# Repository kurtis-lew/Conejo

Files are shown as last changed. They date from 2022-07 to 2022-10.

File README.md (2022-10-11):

# Conejo
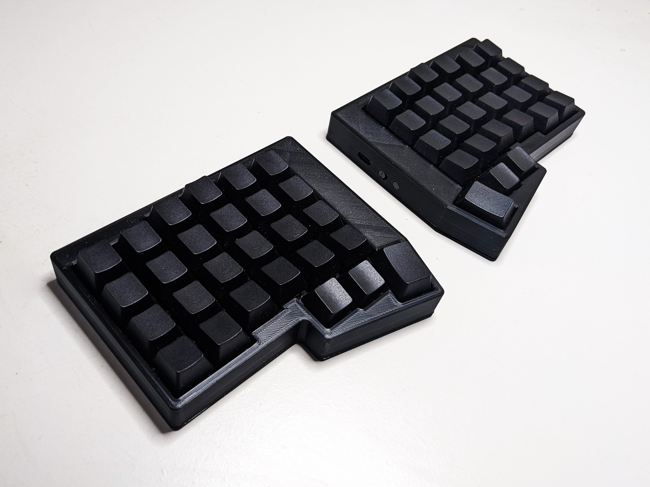
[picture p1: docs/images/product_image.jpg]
Product Image


## Overview

The Conejo is an OSH split, columnar-staggered, 54-key keyboard inspired by the [Iris](https://keeb.io/products/iris-keyboard-split-ergonomic-keyboard), [Lily58](https://github.com/kata0510/Lily58), and [Corne](https://github.com/foostan/crkbd) and powered by the [ZMK Firmware](https://github.com/zmkfirmware/zmk).

For more information, see the [project wiki](https://github.com/kurtis-lew/Conejo/wiki).

## Repository Structure
- KiCAD Project files are located in the root folder
- Gerbers for PCB fabrication are located in `exports/gerbers`.
- `.3mf` files for 3D printing cases are located in `exports/3D`
- An interactive BOM is located in `exports/bom`

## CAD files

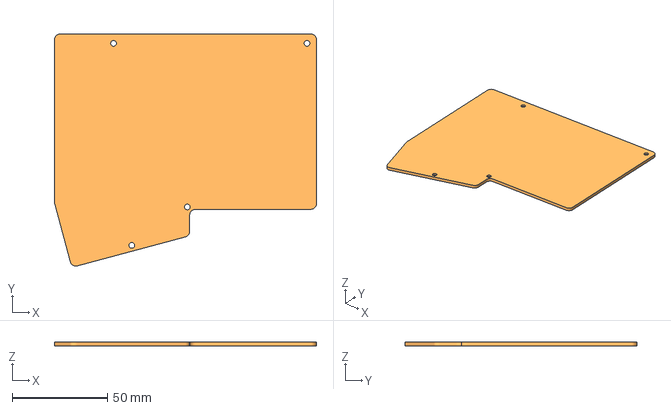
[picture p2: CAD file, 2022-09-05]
exports/3D/Conejo - Bottom Right.3mf
137.8 x 122.1 x 2.00 mm

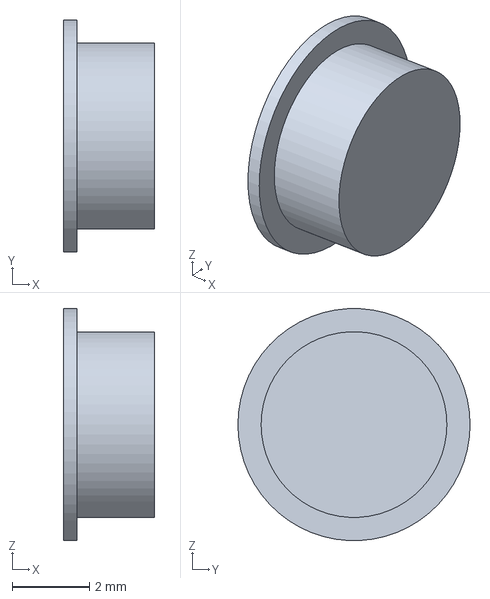
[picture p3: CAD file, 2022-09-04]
exports/3D/Conejo - Reset Button.3mf
2.35 x 6.00 x 6.00 mm

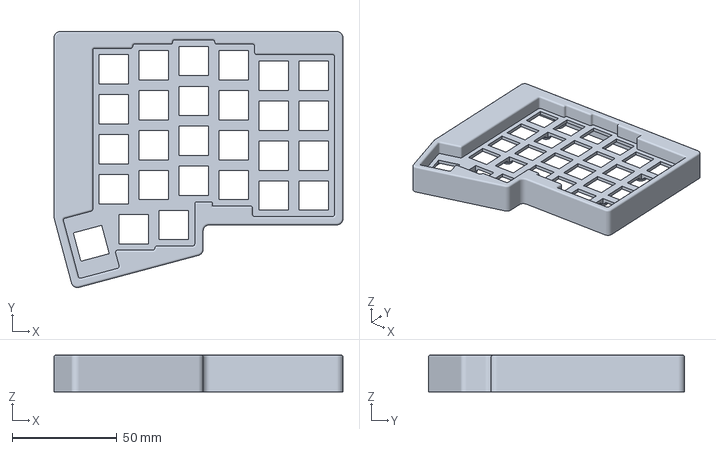
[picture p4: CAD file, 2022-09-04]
exports/3D/Conejo - Top Right.3mf
137.8 x 122.1 x 17.6 mm

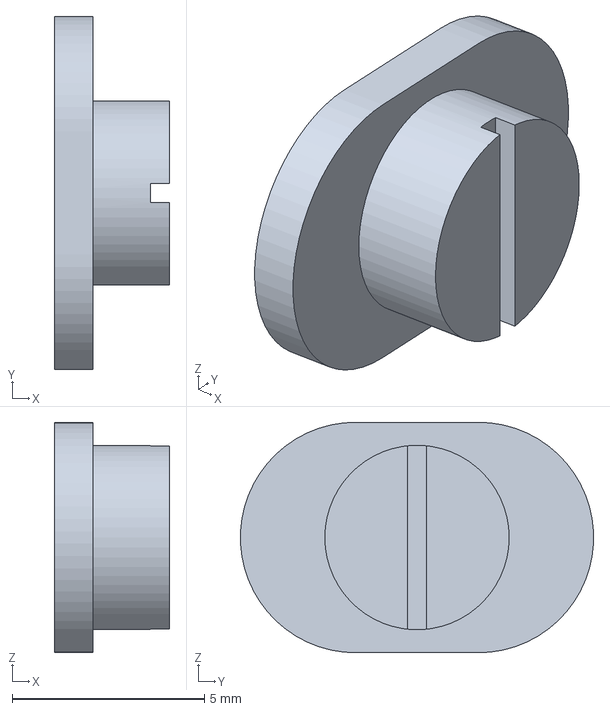
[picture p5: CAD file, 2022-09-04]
exports/3D/Conejo - Power Switch.3mf
3.00 x 9.19 x 6.00 mm

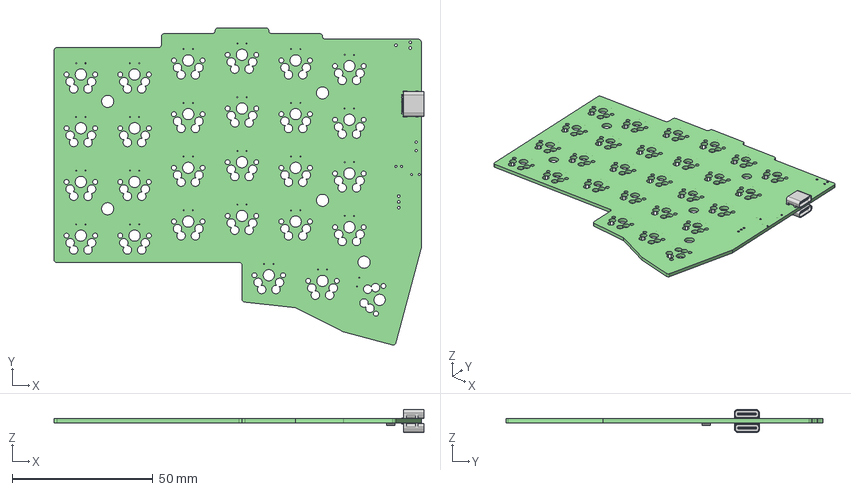
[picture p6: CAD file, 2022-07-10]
exports/3D/Conejo.step
131.2 x 112.5 x 8.17 mm
Conejo PCB

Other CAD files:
exports/3D/Conejo - Bottom Left.3mf
exports/3D/Conejo - Top Left.3mf

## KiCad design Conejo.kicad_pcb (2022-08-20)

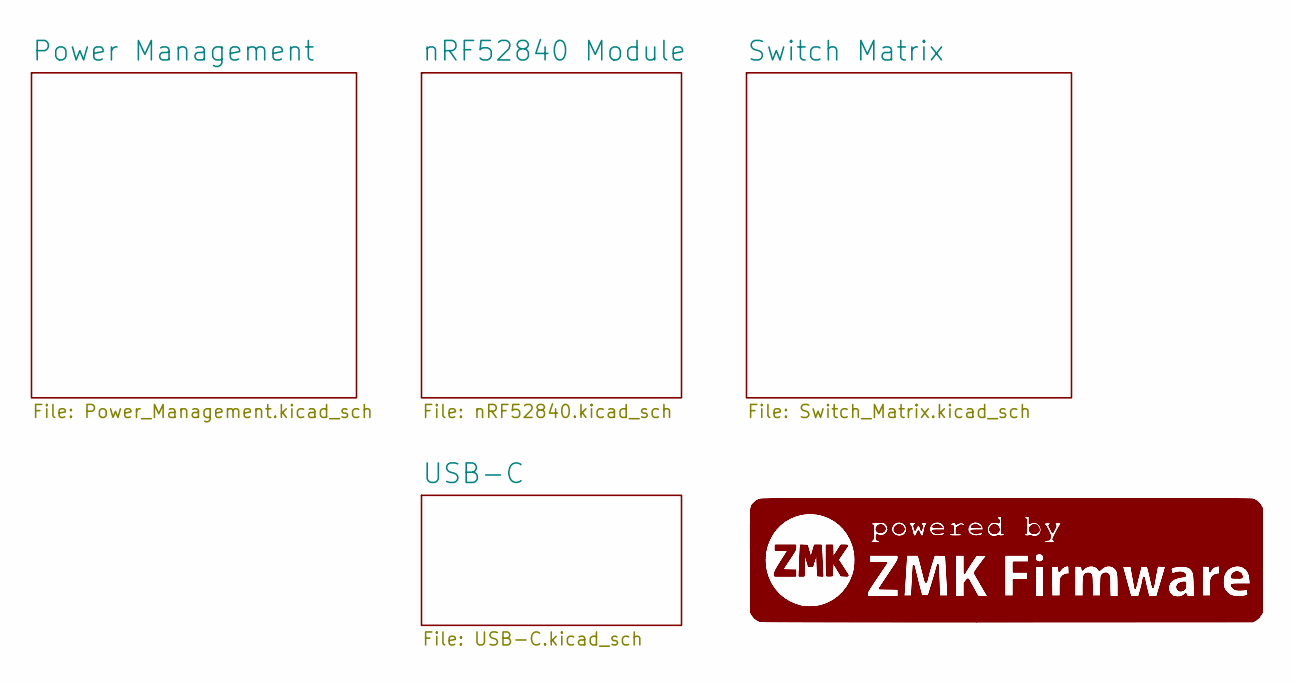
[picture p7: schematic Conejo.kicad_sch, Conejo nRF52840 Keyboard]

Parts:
G1, G2: LOGO; Powered_By_ZMK (Large)

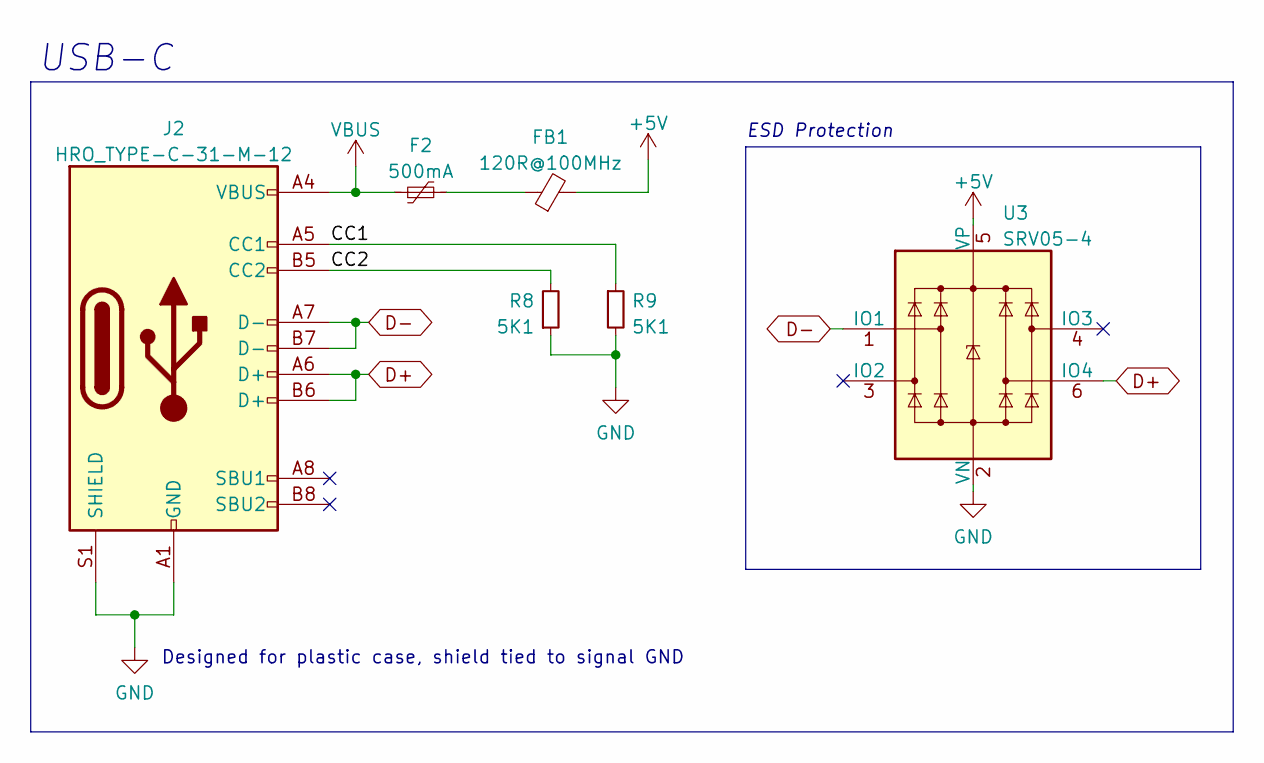
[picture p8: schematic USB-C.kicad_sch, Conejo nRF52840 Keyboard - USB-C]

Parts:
F2: 500mA; Fuse_0603_1608Metric
FB1: 120R@100MHz; L_0402_1005Metric
J2: HRO_TYPE-C-31-M-12; USB_C_Receptacle_HRO_TYPE-C-31-M-12 (Reversible)
R8, R9: 5K1; R_0402_1005Metric
U3: SRV05-4; SOT-23-6-routable

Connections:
+5V: FB1.2, U3.5 (VP); also elsewhere on the board
/USB-C/CC1: J2.A5 (CC1), R9.1
/USB-C/CC2: J2.B5 (CC2), R8.2
D+: J2.A6 (D+), J2.B6 (D+), U3.6 (IO4); also elsewhere on the board
D-: J2.A7 (D-), J2.B7 (D-), U3.1 (IO1); also elsewhere on the board
GND: J2.A1 (GND), J2.A12 (GND), J2.B1 (GND), J2.B12 (GND), J2.S1 (SHIELD), R8.1, R9.2, U3.2 (VN); also elsewhere on the board
unnamed: F2.2, FB1.1
VBUS: F2.1, J2.A4 (VBUS), J2.A9 (VBUS), J2.B4 (VBUS), J2.B9 (VBUS)

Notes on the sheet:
Designed for plastic case, shield tied to signal GND
ESD Protection
USB-C

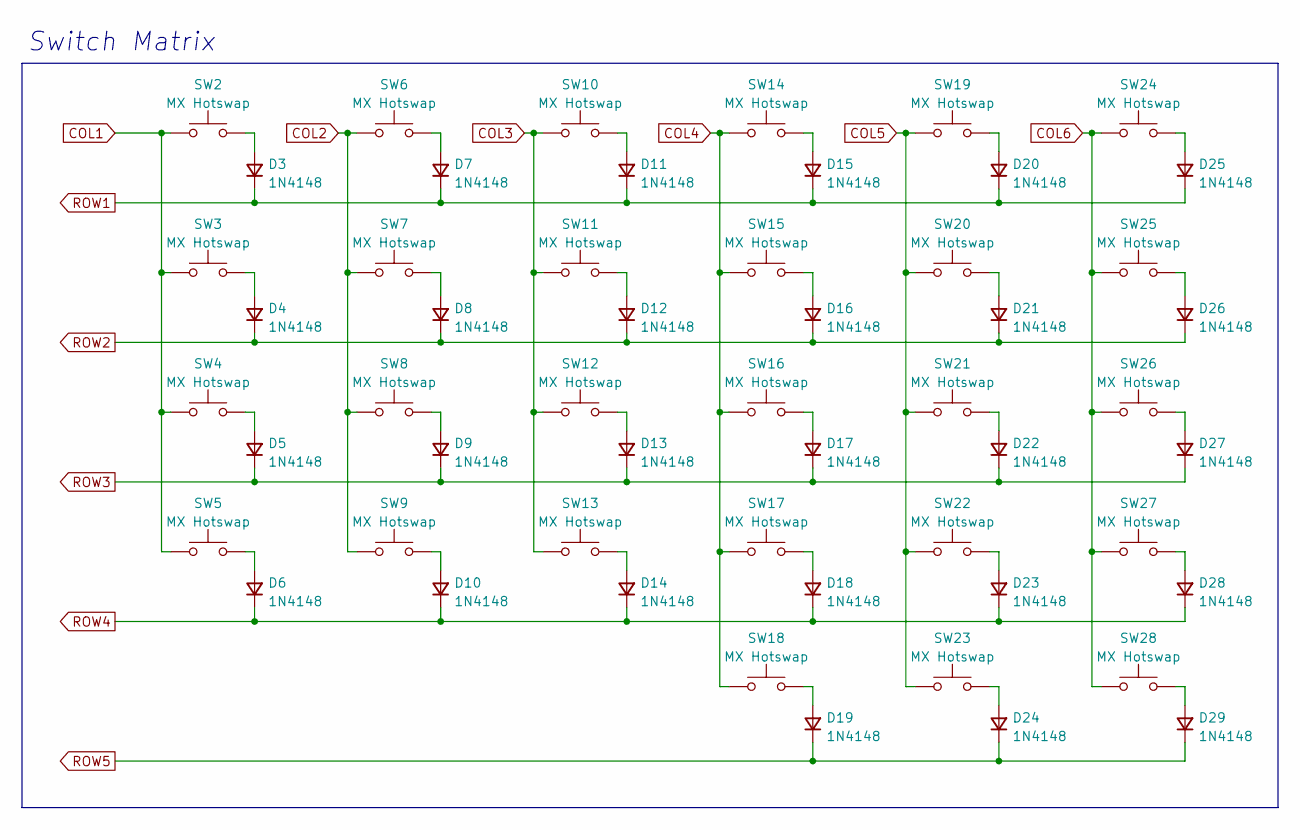
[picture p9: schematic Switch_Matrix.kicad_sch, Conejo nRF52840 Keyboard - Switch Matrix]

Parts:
D3, D4, D5, D6, D7, D8, D9, D10, D11, D12, D13, D14, D15, D16, D17, D18, D19, D20, D21, D22, D23, D24, D25, D26, D27, D28, D29: 1N4148; D_SOD-523 (Reversible)
SW2, SW3, SW4, SW5, SW6, SW7, SW8, SW9, SW10, SW11, SW12, SW13, SW14, SW15, SW16, SW17, SW18, SW19, SW20, SW21, SW22, SW23, SW24, SW25, SW26, SW27: MX Hotswap; MXOnly-1U-Hotswap (Reversible)
SW28: MX Hotswap; MXOnly-1.5U-Hotswap (Reversible)

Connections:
COL1: SW2.1, SW3.1, SW4.1, SW5.1; also elsewhere on the board
COL2: SW6.1, SW7.1, SW8.1, SW9.1; also elsewhere on the board
COL3: SW10.1, SW11.1, SW12.1, SW13.1; also elsewhere on the board
COL4: SW14.1, SW15.1, SW16.1, SW17.1, SW18.1; also elsewhere on the board
COL5: SW19.1, SW20.1, SW21.1, SW22.1, SW23.1; also elsewhere on the board
COL6: SW24.1, SW25.1, SW26.1, SW27.1, SW28.1; also elsewhere on the board
unnamed: D3.2 (A), SW2.2
unnamed: D4.2 (A), SW3.2
unnamed: D5.2 (A), SW4.2
unnamed: D6.2 (A), SW5.2
unnamed: D7.2 (A), SW6.2
unnamed: D8.2 (A), SW7.2
unnamed: D9.2 (A), SW8.2
unnamed: D10.2 (A), SW9.2
unnamed: D11.2 (A), SW10.2
unnamed: D12.2 (A), SW11.2
unnamed: D13.2 (A), SW12.2
unnamed: D14.2 (A), SW13.2
unnamed: D15.2 (A), SW14.2
unnamed: D16.2 (A), SW15.2
unnamed: D17.2 (A), SW16.2
unnamed: D18.2 (A), SW17.2
unnamed: D19.2 (A), SW18.2
unnamed: D20.2 (A), SW19.2
unnamed: D21.2 (A), SW20.2
unnamed: D22.2 (A), SW21.2
unnamed: D23.2 (A), SW22.2
unnamed: D24.2 (A), SW23.2
unnamed: D25.2 (A), SW24.2
unnamed: D26.2 (A), SW25.2
unnamed: D27.2 (A), SW26.2
unnamed: D28.2 (A), SW27.2
unnamed: D29.2 (A), SW28.2
ROW1: D3.1 (K), D7.1 (K), D11.1 (K), D15.1 (K), D20.1 (K), D25.1 (K); also elsewhere on the board
ROW2: D4.1 (K), D8.1 (K), D12.1 (K), D16.1 (K), D21.1 (K), D26.1 (K); also elsewhere on the board
ROW3: D5.1 (K), D9.1 (K), D13.1 (K), D17.1 (K), D22.1 (K), D27.1 (K); also elsewhere on the board
ROW4: D6.1 (K), D10.1 (K), D14.1 (K), D18.1 (K), D23.1 (K), D28.1 (K); also elsewhere on the board
ROW5: D19.1 (K), D24.1 (K), D29.1 (K); also elsewhere on the board

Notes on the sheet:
Switch Matrix

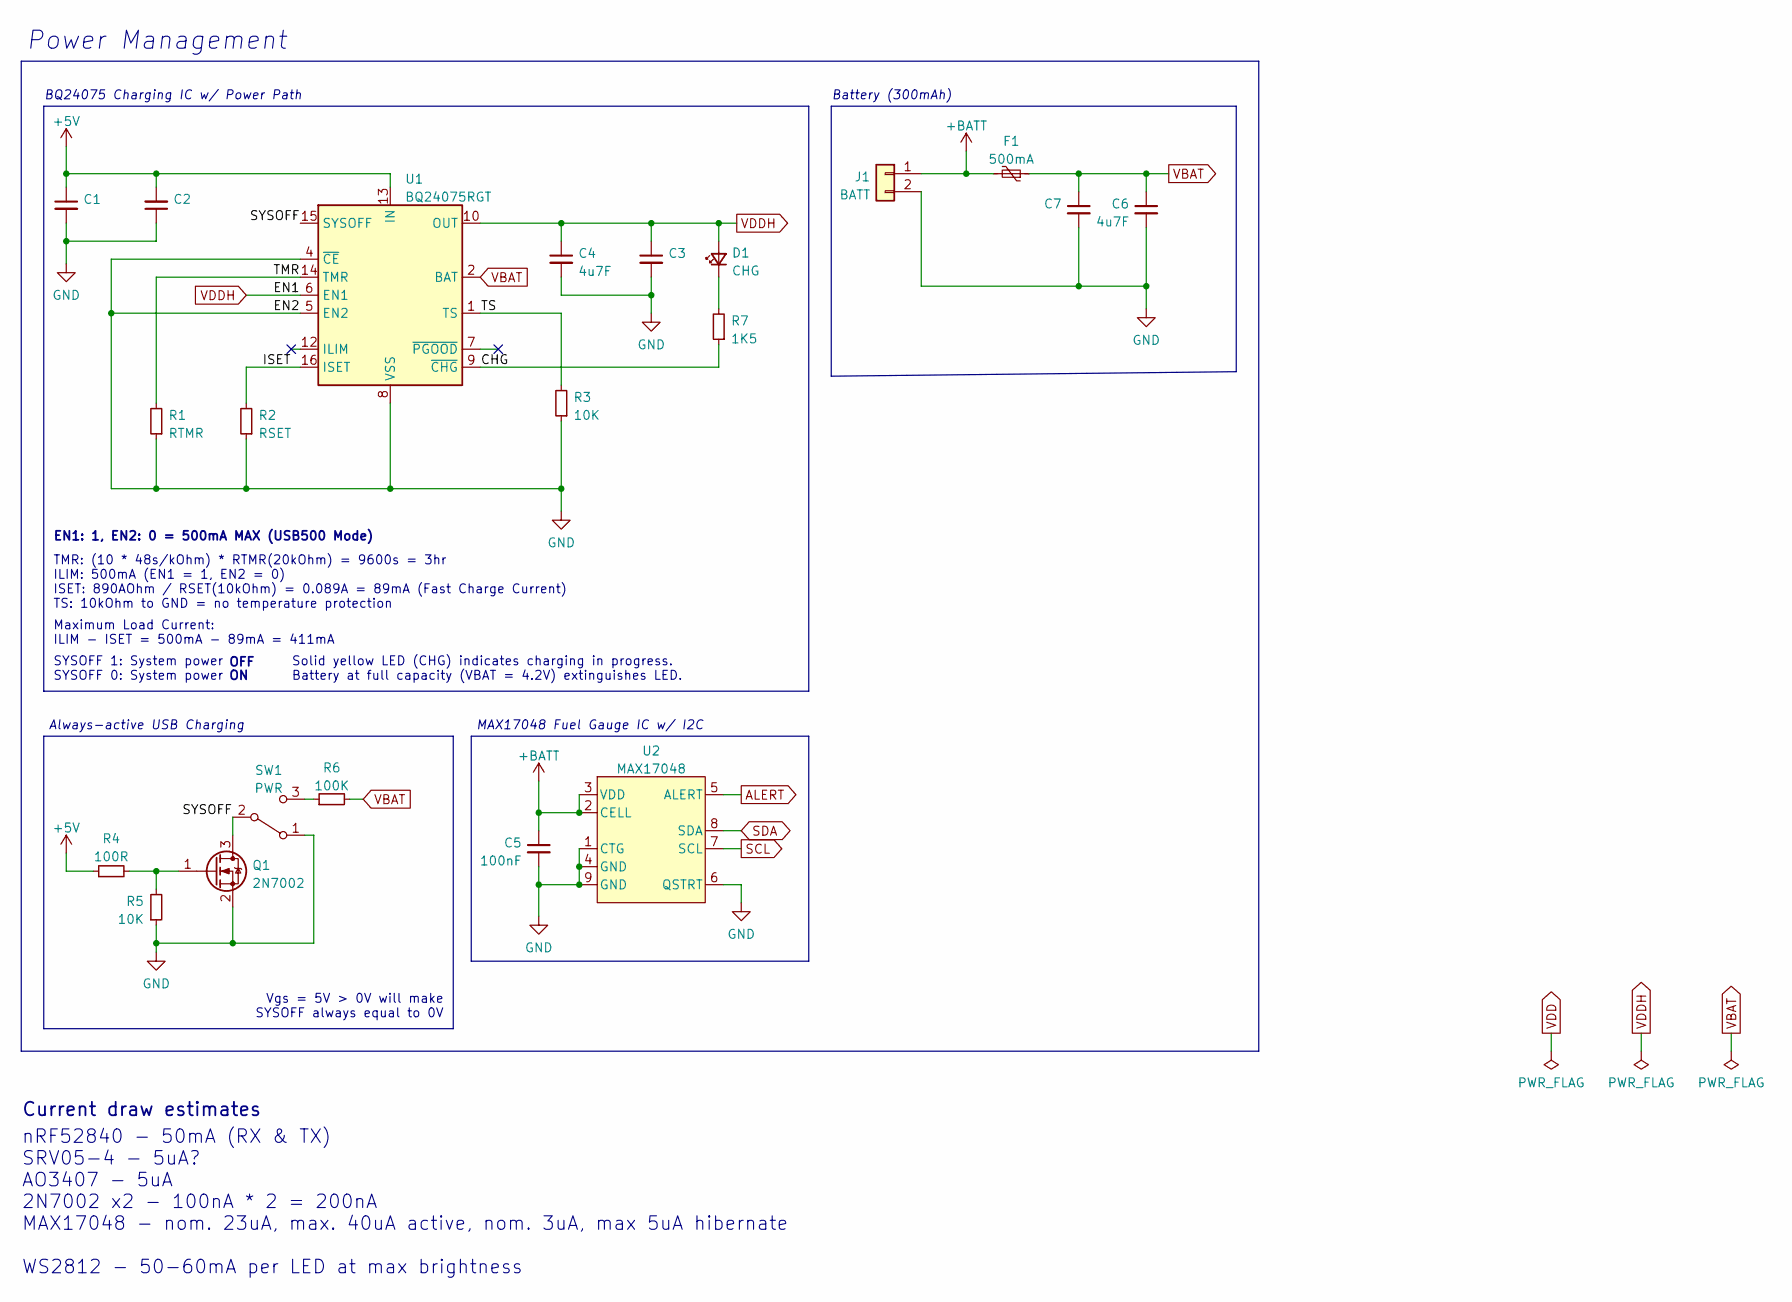
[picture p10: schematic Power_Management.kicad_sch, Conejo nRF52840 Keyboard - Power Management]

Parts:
C1, C2, C3, C7: (no value)
C4, C6: 4u7F; C_0402_1005Metric
C5: 100nF; C_0402_1005Metric
D1: CHG; LED_1206_3216Metric (Reversible)
F1: 500mA; Fuse_0603_1608Metric
J1: BATT; Battery Header
Q1: 2N7002; SOT-23
R1: RTMR; R_0402_1005Metric
R2: RSET; R_0402_1005Metric
R3, R5: 10K; R_0402_1005Metric
R4: 100R; R_0402_1005Metric
R6: 100K; R_0402_1005Metric
R7: 1K5; R_0402_1005Metric
SW1: PWR; SW_MSK12C02-HB (Reversible)
U1: BQ24075RGT; VQFN-16-1EP_3x3mm_P0.5mm_EP1.6x1.6mm
U2: MAX17048; TDFN-8-1EP_2x2mm_P0.5mm_EP0.8x1.2mm

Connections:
+5V: C1.1, C2.2, R4.1, U1.13 (IN); also elsewhere on the board
+BATT: C5.1, F1.2, J1.1, U2.2 (CELL), U2.3 (VDD)
/Power Management/CHG: R7.1, U1.9 (~CHG)
/Power Management/ISET: R2.2, U1.16 (ISET)
/Power Management/SYSOFF: Q1.3 (D), SW1.2 (B), U1.15 (SYSOFF)
/Power Management/TMR: R1.2, U1.14 (TMR)
/Power Management/TS: R3.2, U1.1 (TS)
ALERT: U2.5 (ALERT); also elsewhere on the board
GND: C1.2, C2.1, C3.2, C4.2, C5.2, C6.2, C7.2, J1.2, Q1.2 (S), R1.1, R2.1, R3.1, R5.1, SW1.1 (A), U1.4 (~CE), U1.5 (EN2), U1.8 (VSS), U1.17 (VSS), U2.1 (CTG), U2.4 (GND), U2.6 (QSTRT), U2.9 (GND); also elsewhere on the board
unnamed: D1.1 (K), R7.2
unnamed: Q1.1 (G), R4.2, R5.2
unnamed: R6.1, SW1.3 (C)
SCL: U2.7 (SCL); also elsewhere on the board
SDA: U2.8 (SDA); also elsewhere on the board
VBAT: C6.1, C7.1, F1.1, R6.2, U1.2 (BAT), U1.3 (BAT)
VDDH: C3.1, C4.1, D1.2 (A), U1.6 (EN1), U1.10 (OUT), U1.11 (OUT); also elsewhere on the board

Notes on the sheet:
Always-active USB Charging
EN1: 1, EN2: 0 = 500mA MAX (USB500 Mode)
TMR: (10 * 48s/kOhm) * RTMR(20kOhm) = 9600s = 3hr ILIM: 500mA (EN1 = 1, EN2 = 0) ISET: 890AOhm / RSET(10kOhm) = 0.089A = 89mA (Fast Charge Current) TS: 10kOhm to GND = no temperature protection
MAX17048 Fuel Gauge IC w/ I2C
nRF52840 - 50mA (RX & TX) SRV05-4 - 5uA? AO3407 - 5uA 2N7002 x2 - 100nA * 2 = 200nA MAX17048 - nom. 23uA, max. 40uA active, nom. 3uA, max 5uA hibernate WS2812 - 50-60mA per LED at max brightness
BQ24075 Charging IC w/ Power Path
Maximum Load Current: ILIM - ISET = 500mA - 89mA = 411mA
Battery (300mAh)
SYSOFF 1: System power SYSOFF 0: System power
Vgs = 5V > 0V will make SYSOFF always equal to 0V
Solid yellow LED (CHG) indicates charging in progress. Battery at full capacity (VBAT = 4.2V) extinguishes LED.
Current draw estimates
Power Management
OFF

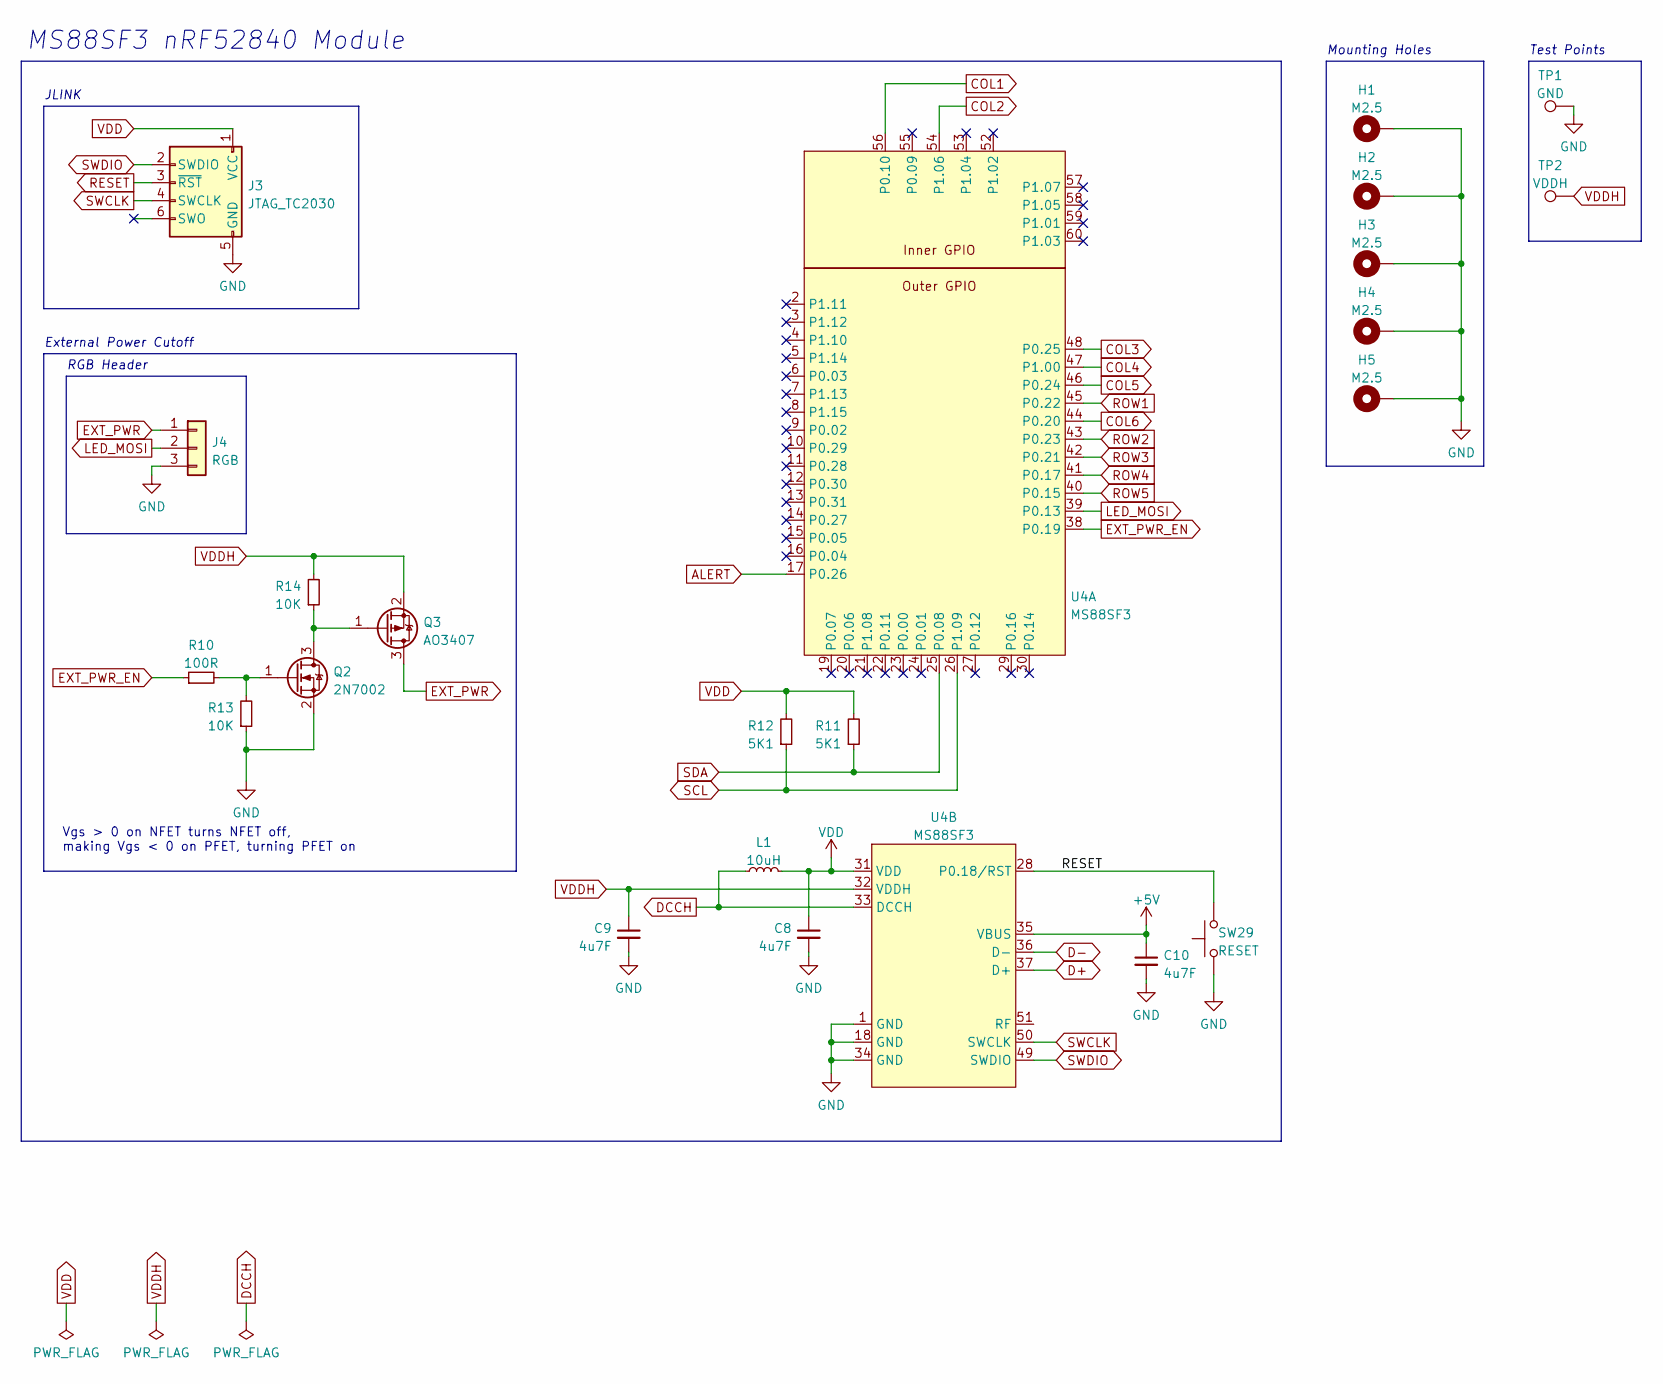
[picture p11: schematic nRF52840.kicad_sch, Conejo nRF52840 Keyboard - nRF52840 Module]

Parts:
C8, C9, C10: 4u7F; C_0402_1005Metric
H1, H2, H3, H4, H5: M2.5; MountingHole_2.7mm_Pad_Via
J3: JTAG_TC2030; CON_TC2030_outlined
J4: RGB; LED Header
L1: 10uH; L_0603_1608Metric
Q2: 2N7002; SOT-23
Q3: AO3407; SOT-23
R10: 100R; R_0402_1005Metric
R11, R12: 5K1; R_0603_1608Metric
R13, R14: 10K; R_0402_1005Metric
SW29: RESET; Panasonic_EVQPUL_EVQPUC (Reversible)
TP1: GND; TestPoint_THTPad_1.0x1.0mm_Drill0.5mm
TP2: VDDH; TestPoint_Pad_D1.0mm
U4: MS88SF3; MS88SF3_V2

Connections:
+5V: C10.1, U4.35 (VBUS); also elsewhere on the board
ALERT: U4.17 (P0.26); also elsewhere on the board
COL1: U4.56 (P0.10); also elsewhere on the board
COL2: U4.54 (P1.06); also elsewhere on the board
COL3: U4.48 (P0.25); also elsewhere on the board
COL4: U4.47 (P1.00); also elsewhere on the board
COL5: U4.46 (P0.24); also elsewhere on the board
COL6: U4.44 (P0.20); also elsewhere on the board
D+: U4.37 (D+); also elsewhere on the board
D-: U4.36 (D-); also elsewhere on the board
DCCH: L1.1, U4.33 (DCCH)
EXT_PWR: J4.1, Q3.3 (D)
EXT_PWR_EN: R10.1, U4.38 (P0.19)
GND: C8.2, C9.2, C10.2, H1.1, H2.1, H3.1, H4.1, H5.1, J3.5 (GND), J4.3, Q2.2 (S), R13.1, SW29.1, TP1.1, U4.1 (GND), U4.18 (GND), U4.34 (GND); also elsewhere on the board
LED_MOSI: J4.2, U4.39 (P0.13)
unnamed: Q2.1 (G), R10.2, R13.2
unnamed: Q2.3 (D), Q3.1 (G), R14.1
RESET: J3.3 (~RST), SW29.2, U4.28 (P0.18/RST)
ROW1: U4.45 (P0.22); also elsewhere on the board
ROW2: U4.43 (P0.23); also elsewhere on the board
ROW3: U4.42 (P0.21); also elsewhere on the board
ROW4: U4.41 (P0.17); also elsewhere on the board
ROW5: U4.40 (P0.15); also elsewhere on the board
SCL: R12.1, U4.26 (P1.09); also elsewhere on the board
SDA: R11.1, U4.25 (P0.08); also elsewhere on the board
SWCLK: J3.4 (SWCLK), U4.50 (SWCLK)
SWDIO: J3.2 (SWDIO), U4.49 (SWDIO)
VDD: C8.1, J3.1 (VCC), L1.2, R11.2, R12.2, U4.31 (VDD)
VDDH: C9.1, Q3.2 (S), R14.2, TP2.1, U4.32 (VDDH); also elsewhere on the board

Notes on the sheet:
Test Points
RGB Header
Vgs > 0 on NFET turns NFET off, making Vgs < 0 on PFET, turning PFET on
JLINK
MS88SF3 nRF52840 Module
External Power Cutoff
Mounting Holes

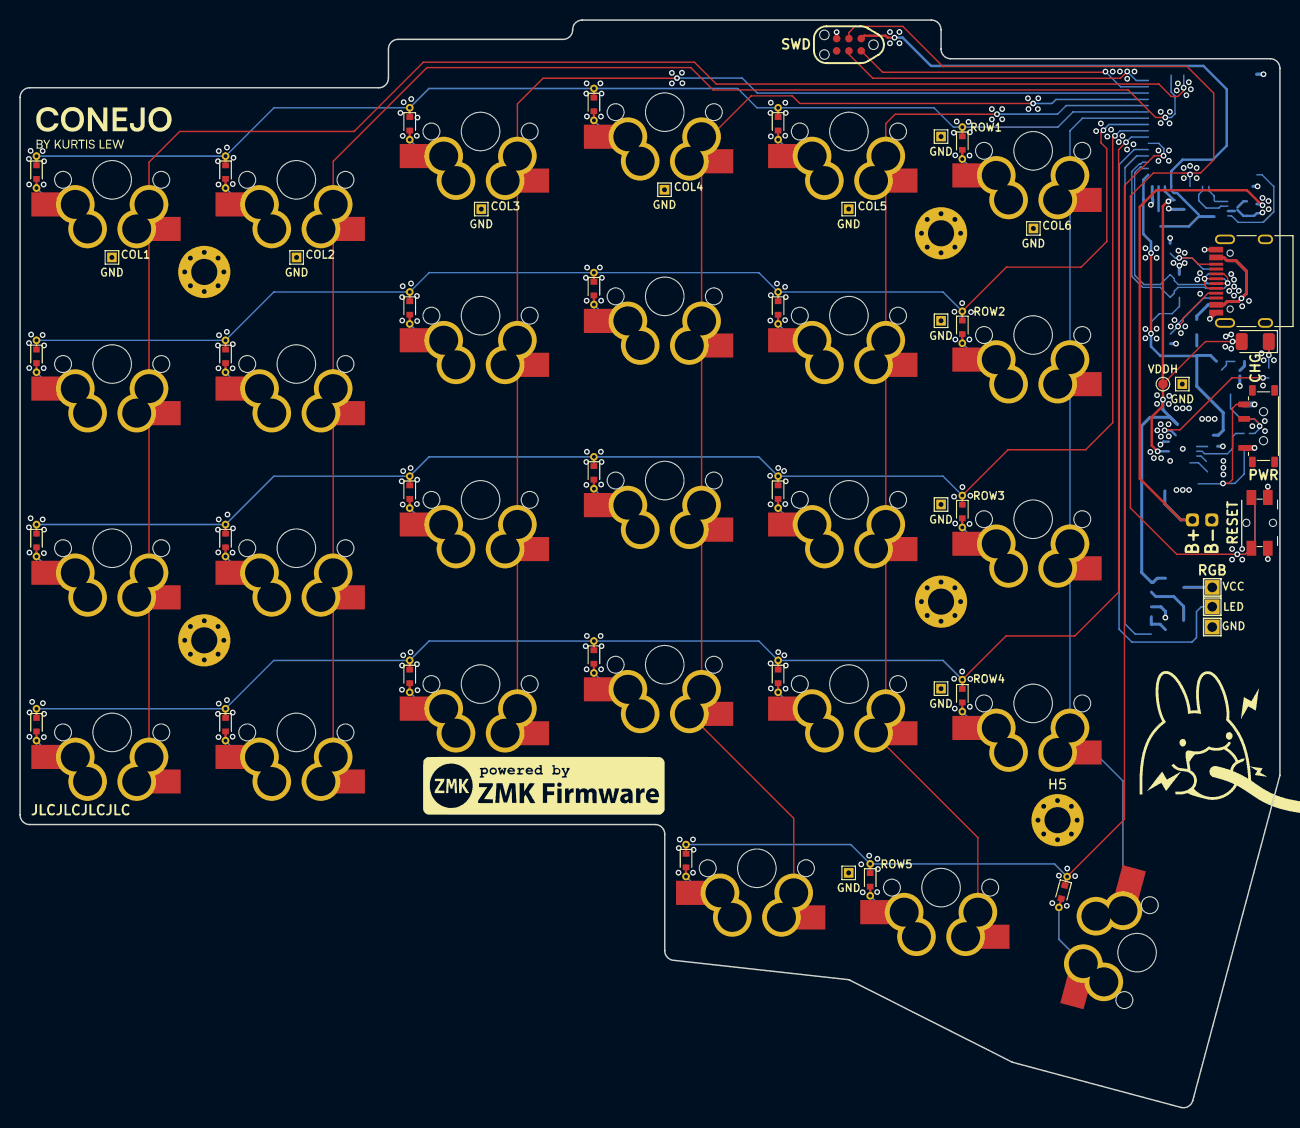
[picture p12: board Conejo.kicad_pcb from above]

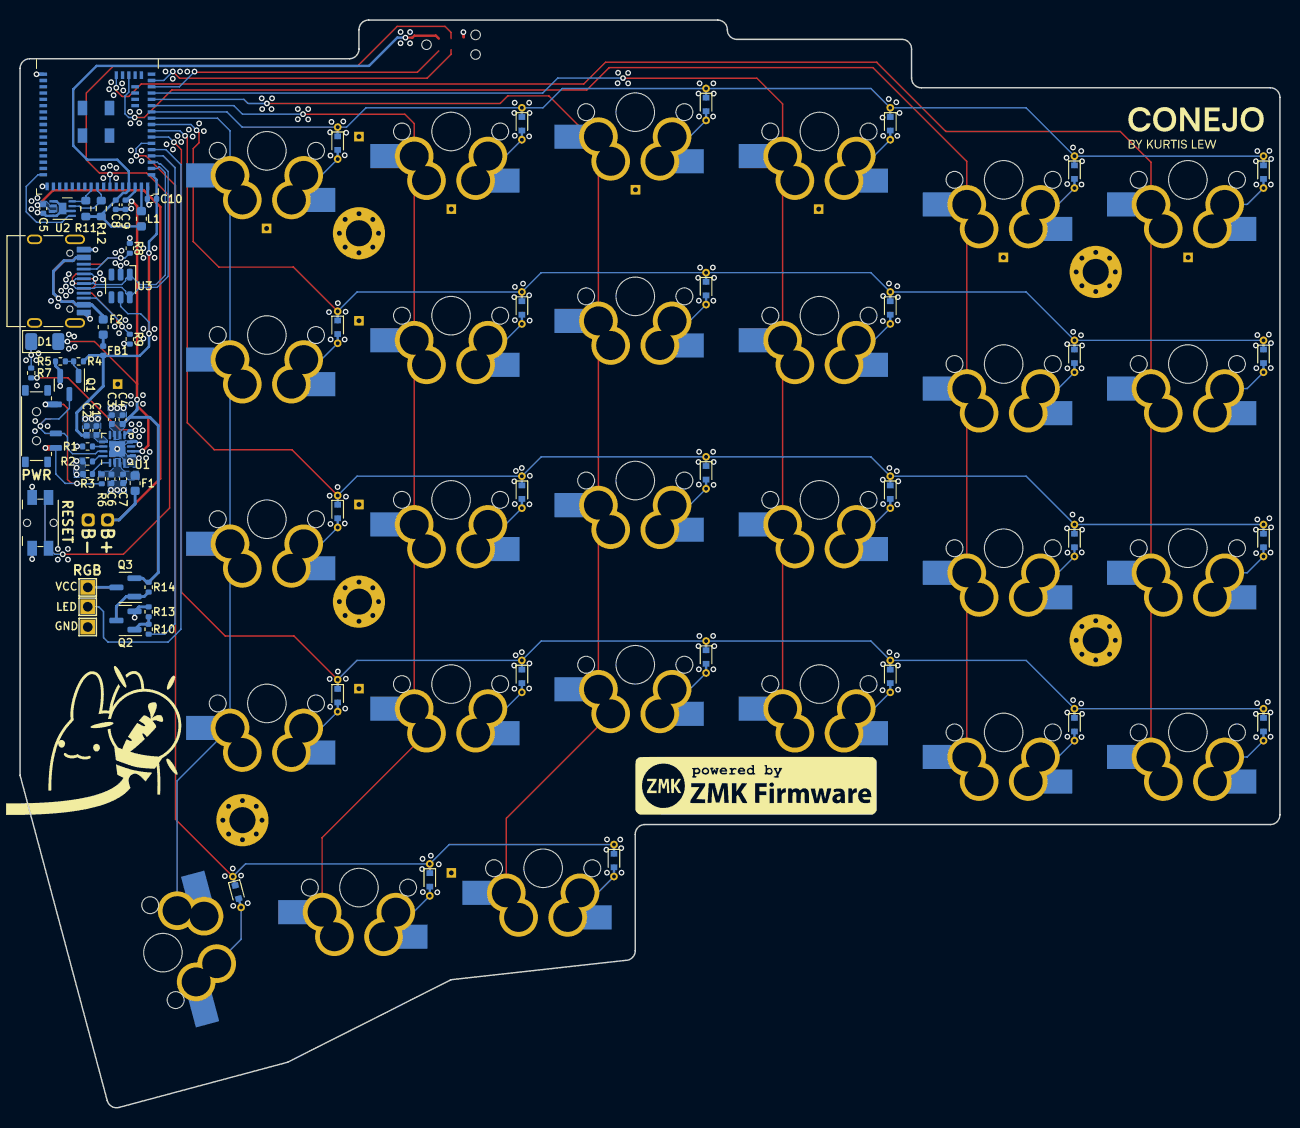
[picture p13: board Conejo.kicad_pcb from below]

Board: 4 copper layers, 130.3 x 112.5 mm, 116 parts (40 on the bottom side), 70 nets.

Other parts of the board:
TP1#2, TP1#3, TP1#4, TP1#5, TP1#6, TP1#7, TP1#8, TP1#9, TP1#10, TP1#11, TP1#12: GND; TestPoint_THTPad_1.0x1.0mm_Drill0.5mm

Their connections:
GND: TP1#2.1, TP1#3.1, TP1#4.1, TP1#5.1, TP1#6.1, TP1#7.1, TP1#8.1, TP1#9.1, TP1#10.1, TP1#11.1, TP1#12.1; also elsewhere on the board

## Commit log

2022-07-09 feat(pcb): Version 0.1
    [Athena54-B_Cu.gbr, Athena54-B_Mask.gbr, Athena54-B_Paste.gbr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]
2022-07-09 fix(pcb): Move USB-C 1.5mm closer to the edge
    [Athena54-B_Cu.gbr, Athena54-B_Mask.gbr, Athena54-B_Paste.gbr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]
2022-07-09 fix(pcb): Move thumb cluster in by 3mm
    [Athena54-B_Cu.gbr, Athena54-B_Mask.gbr, Athena54-B_Paste.gbr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]
2022-07-09 feat(pcb): Version 0.2
    [Athena54-B_Cu.gbr, Athena54-B_Mask.gbr, Athena54-B_Paste.gbr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]
2022-07-09 feat(pcb): Version 0.2.1
    [Athena54-B_Cu.gbr, Athena54-B_Mask.gbr, Athena54-B_Paste.gbr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]
2022-07-09 fix(schematic): Adjust charging parameters
    [Athena54.kicad_pcb, Athena54.kicad_sch, Power_Management.kicad_sch]
2022-07-09 fix(pcb): Update column stagger measurement table
    [Athena54.kicad_pcb]
2022-07-09 fix(3D): Re-export 3D model for case design
2022-07-09 fix(schematic): Fix links to footprints
    [Athena54.kicad_pcb, Athena54.kicad_sch, Power_Management.kicad_sch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]
2022-07-10 fix(pcb): Add fillet to thumb cluster edge cut
    [Athena54-B_Cu.gbr, Athena54-B_Mask.gbr, Athena54-B_Paste.gbr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]
2022-07-10 fix(schematic): Delete Moko_MK08A.kicad_sch
    [Moko_MK08A.kicad_sch]
2022-07-10 refactor!!!(repository): Rename from Athena54 to Conejo
    [Athena54-B_Cu.gbr, Athena54-B_Mask.gbr, Athena54-B_Paste.gbr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]
2022-07-10 fix(schematic): Further updates to referencing footprints and symbols
    [Conejo.kicad_pcb, Conejo.kicad_sch, Power_Management.kicad_sch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]
2022-07-10 refactor(pcb): Update paths to 3D models, whole board .STEP
    Delete EVQPU-LC-02K.STEP
    [Conejo-B_Cu.gbr, Conejo-B_Mask.gbr, Conejo-B_Paste.gbr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]
2022-07-11 feat(pcb): Version 0.2.2
    - Update MS88SF3 footprint
    - Create thumb cluster silksscreen
    - Separate NTPH and PTH drill files
    [Conejo-B_Cu.gbr, Conejo-B_Mask.gbr, Conejo-B_Paste.gbr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]
2022-07-12 fix(pcb): Finalize part selection
    [Conejo.kicad_pcb, Conejo.kicad_sch, nRF52840.kicad_sch]
2022-07-13 fix(schematic): Fix inductor value in DCCH LC filter
    [nRF52840.kicad_sch]
2022-07-13 feat(pcb): Version 0.2.3
    - Switched vertical traces on matrix to back copper
    - Added GND vias for all diodes
    [Conejo-B_Cu.gbr, Conejo-B_Mask.gbr, Conejo-B_Paste.gbr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]
2022-07-15 feat(pcb): Version 0.3
    - Move components entirely to back copper :tada:
    - Update silkscreen legibility to enhance ease of component placement
    - Fix I2C pullup resistors
    - Replace incorrect value of 1K5 with 5K1
    - Update footprint to 0603_1608 to fit VDD traces underneath, compared to original 0402_1005 footprint
    - Increase text width on RESET button, POWER Switch, and CHG LED
    [Conejo-B_Cu.gbr, Conejo-B_Mask.gbr, Conejo-B_Paste.gbr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]
2022-07-15 fix(pcb): Update RGB header component placement
    [Conejo-B_Cu.gbr, Conejo-B_Mask.gbr, Conejo-B_Paste.gbr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]
2022-07-16 feat(pcb): Version 0.3.1
    [Conejo-B_Cu.gbr, Conejo-B_Mask.gbr, Conejo-B_Paste.gbr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]
2022-07-17 feat(pcb): Version 0.3.2
    - Move TC2030 footprint to accessible location
    - Move diodes to be outside of 14mmx14mm switch area
    - Update BOM to remove footprints that don't require placement
    [Conejo-B_Cu.gbr, Conejo-B_Mask.gbr, Conejo-B_Paste.gbr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]
2022-07-17 fix(pcb): Update Gerbers with JLCPCB order number location
    [Conejo-B_Cu.gbr, Conejo-B_Mask.gbr, Conejo-B_Paste.gbr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]
2022-07-17 feat(schematic): Add titles and individual sheet comments
    [Power_Management.kicad_sch, Switch_Matrix.kicad_sch, USB-C.kicad_sch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]
2022-07-21 feat(pcb): Version 0.4
    - Prepare to move from JLC7628 stackup to JLC3313 stackup (Lowers dielectric constant from 4.6 to 4.05)
    - Increase mounting hole diameter back to 5.4mm
    - 6mil signals, 10mil power, 13 mil vias
    - 3W spacing wherever possible
    [Conejo-B_Cu.gbr, Conejo-B_Mask.gbr, Conejo-B_Paste.gbr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]
2022-07-21 fix(pcb): Re-check GND vias around diodes
    [Conejo-B_Cu.gbr, Conejo-B_Mask.gbr, Conejo-B_Paste.gbr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]
2022-07-22 feat(pcb): Version 0.4.1
    - Add oscilloscope probing pads/labels
    [Conejo-B_Cu.gbr, Conejo-B_Mask.gbr, Conejo-B_Paste.gbr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]
2022-07-30 feat(pcb): Switch from 4.3mm NPTH mounting holes to M2 PTH
    [Conejo-B_Cu.gbr, Conejo-B_Mask.gbr, Conejo-B_Paste.gbr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]
2022-08-01 feat(3D): Re-export model with M2 holes
2022-08-07 feat(pcb): Version 0.4.2
    - Add nameplate
    - Increase mounting hole size to M2.5
    [Conejo-B_Cu.gbr, Conejo-B_Mask.gbr, Conejo-B_Paste.gbr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]
2022-08-08 feat(pcb): Update ConejoPlug.kicad_mod
    - Give the bunny elbows!
    [Conejo-B_Cu.gbr, Conejo-B_Mask.gbr, Conejo-B_Paste.gbr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]
2022-08-20 feat(pcb): Version 1.0.0
    - Change decoupling capacitors from 4.7uF/1uF pairs to both 4.7uF
    [Conejo.kicad_pcb, Conejo.kicad_sch, Power_Management.kicad_sch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]
2022-08-21 fix(pcb/bom): Remove test points from BOM
2022-09-04 feat(3D): Export case models
    [Conejo - Power Switch.3mf, Conejo - Reset Button.3mf, Conejo - Top Left.3mf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]
2022-09-05 feat(3D): Export bottom covers
    [Conejo - Bottom Left.3mf, Conejo - Bottom Right.3mf]
